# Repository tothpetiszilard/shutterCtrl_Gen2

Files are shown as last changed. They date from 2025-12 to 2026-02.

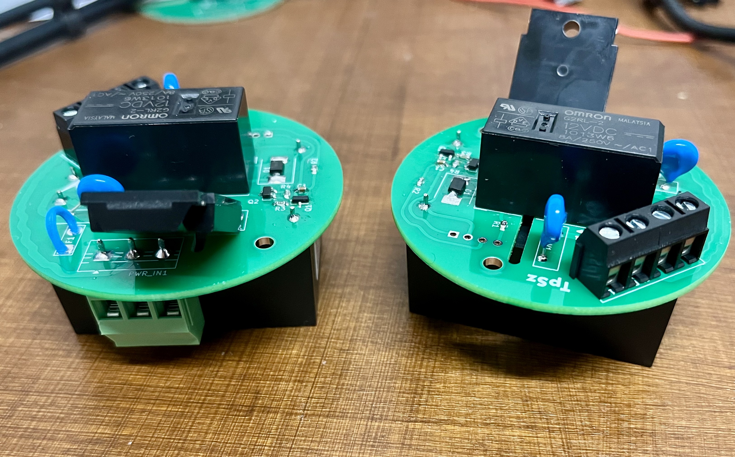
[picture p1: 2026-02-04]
pwr/images/IMG_6767.jpg

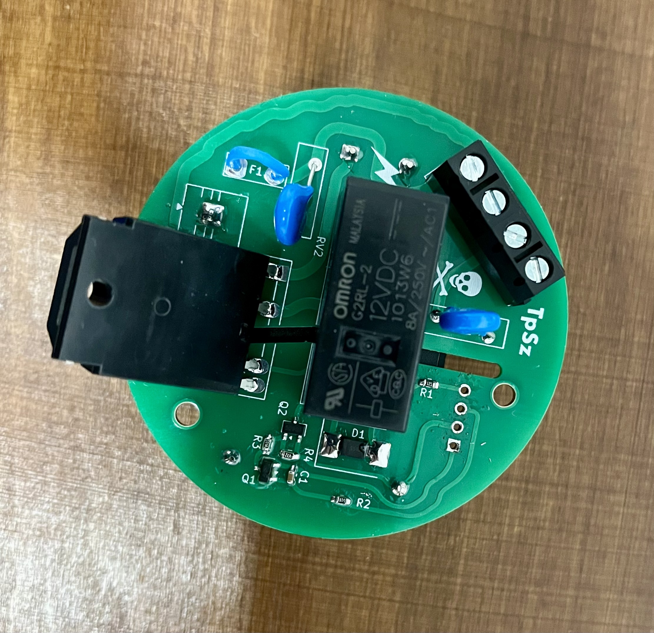
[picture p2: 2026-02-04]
pwr/images/IMG_6769.jpg

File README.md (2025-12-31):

# Development of an electric window shutter motor controller
- This is the second version of my project -> First version use two SSRs, this one use one SSR (zero-cross) and one relay
- The plan is to first select the direction with the relay, then turn on the motor with the SSR
- Varistors are not optional, they are required to protect the electronics
- There will be two boards, one for the high voltage components and one for the control logic
- There is a standard shutter ctrl switch (legrand) in the wall with 3 wires, that will be also utilized and will be connected to the controller board
- Shutter motor is generic, no electronic control, only internal end-stop switches (NC)
- Whole stuff should fit into an european standard 80mm round electric box
- Optional IR led is available on the controller board to control the AC units in the rooms (experimental)

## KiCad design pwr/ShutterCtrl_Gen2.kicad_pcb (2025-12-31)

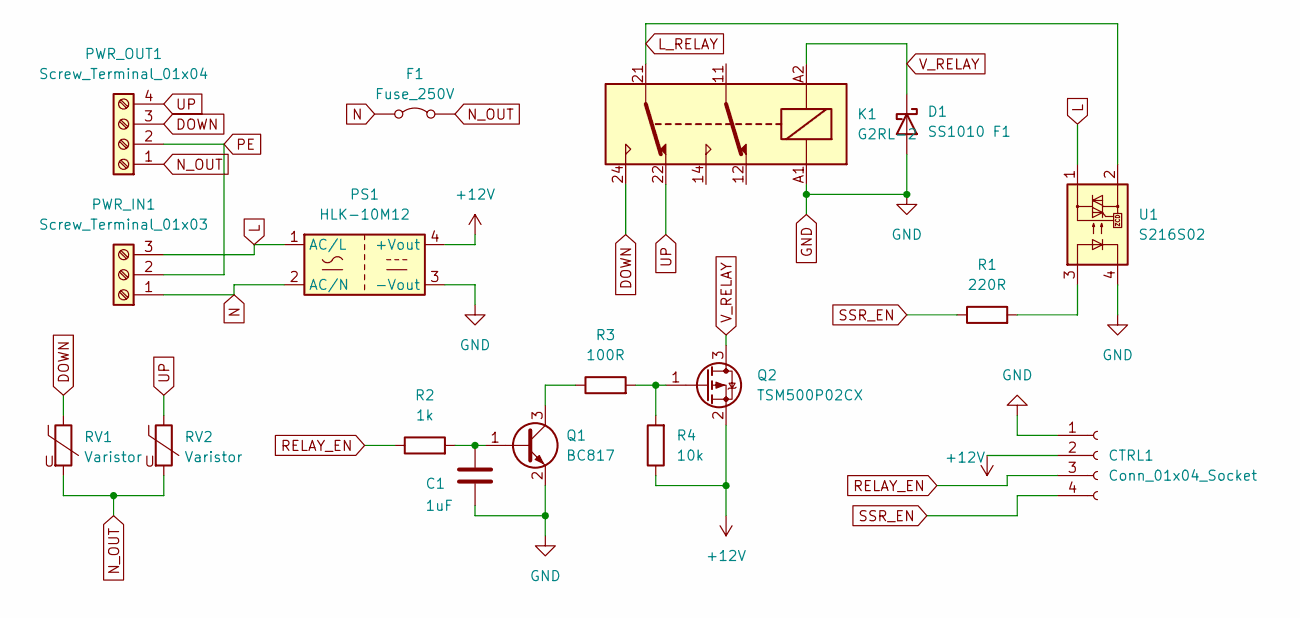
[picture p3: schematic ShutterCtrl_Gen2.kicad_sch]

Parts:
C1: 1uF; C_0603_1608Metric_Pad1.08x0.95mm_HandSolder
CTRL1: Conn_01x04_Socket; PinHeader_1x04_P2.54mm_Vertical
D1: SS1010 F1; D_SMC
F1: Fuse_250V; TestPoint_2Pads_Pitch5.08mm_Drill1.3mm
K1: G2RL-2; Relay_DPDT_Omron_G2RL-2
PS1: HLK-10M12; Converter_ACDC_Hi-Link_HLK-10Mxx
PWR_IN1: Screw_Terminal_01x03; TerminalBlock_MaiXu_MX126-5.0-03P_1x03_P5.00mm
PWR_OUT1: Screw_Terminal_01x04; TerminalBlock_MaiXu_MX126-5.0-04P_1x04_P5.00mm
Q1: BC817; SOT-23
Q2: TSM500P02CX; SOT-23
R1: 220R; R_0201_0603Metric_Pad0.64x0.40mm_HandSolder
R2: 1k; R_0201_0603Metric_Pad0.64x0.40mm_HandSolder
R3: 100R; R_0201_0603Metric_Pad0.64x0.40mm_HandSolder
R4: 10k; R_0201_0603Metric_Pad0.64x0.40mm_HandSolder
RV1, RV2: Varistor; RV_Disc_D12mm_W3.9mm_P7.5mm
U1: S216S02; SIP4_Sharp-SSR_P7.62mm_Straight

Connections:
+12V: CTRL1.2, PS1.4 (+Vout), Q2.2 (S), R4.1
DOWN: K1.24, PWR_OUT1.3, RV1.1
GND: C1.2, CTRL1.1, D1.2 (A), K1.A1, PS1.3 (-Vout), Q1.2 (E), U1.4
L: PS1.1 (AC/L), PWR_IN1.3, U1.1
L_RELAY: K1.21, U1.2
N: F1.1 (A), PS1.2 (AC/N), PWR_IN1.1
N_OUT: F1.2 (B), PWR_OUT1.1, RV1.2, RV2.2
unnamed: C1.1, Q1.1 (B), R2.2
unnamed: Q1.3 (C), R3.1
unnamed: Q2.1 (G), R3.2, R4.2
unnamed: R1.2, U1.3
PE: PWR_IN1.2, PWR_OUT1.2
RELAY_EN: CTRL1.3, R2.1
SSR_EN: CTRL1.4, R1.1
UP: K1.22, PWR_OUT1.4, RV2.1
V_RELAY: D1.1 (K), K1.A2, Q2.3 (D)

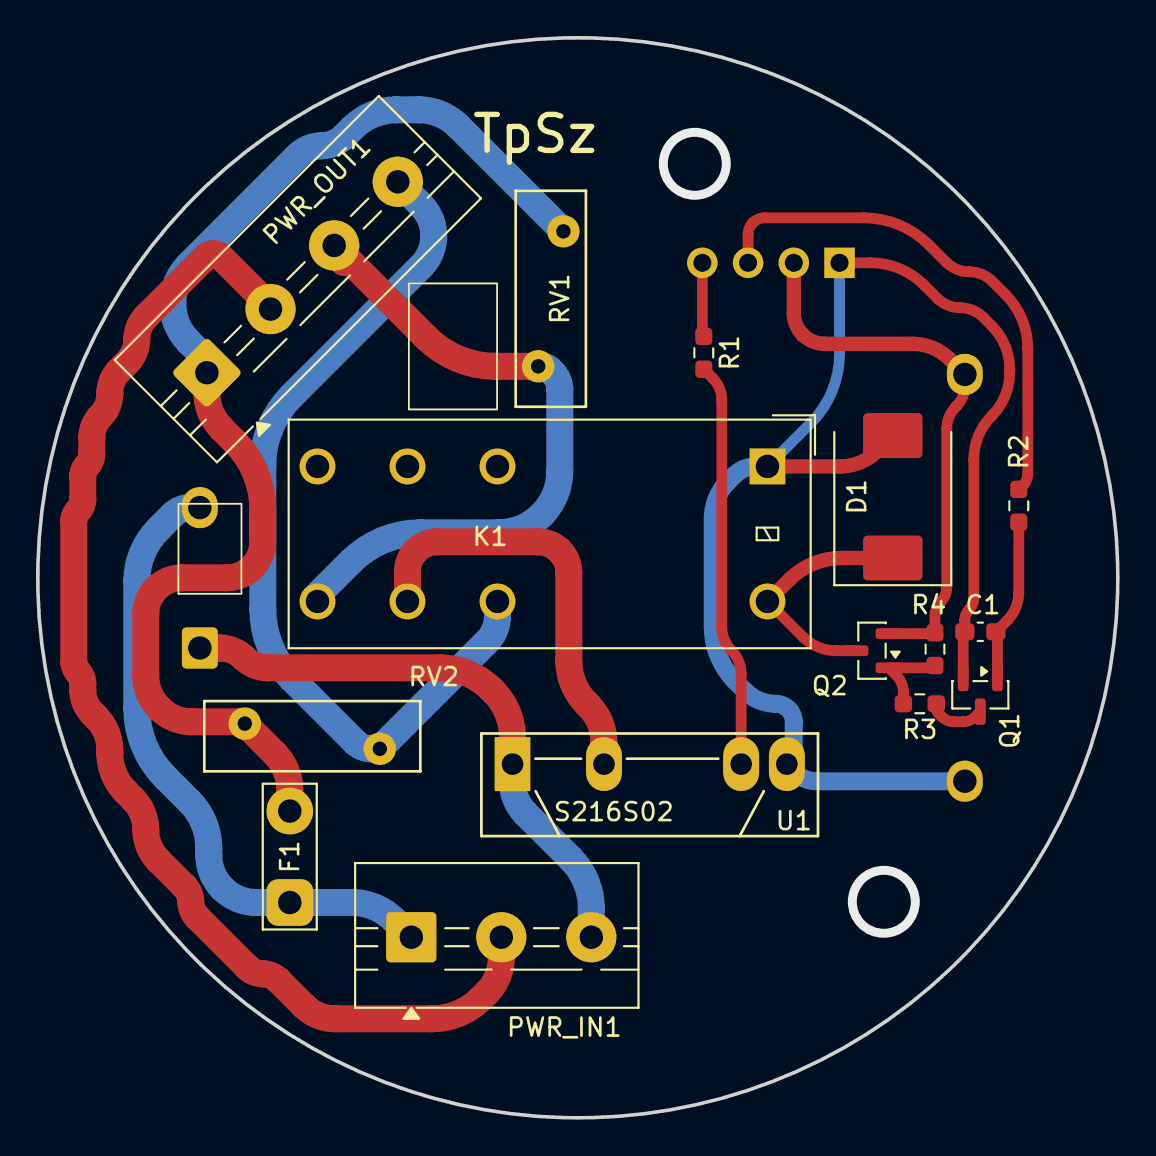
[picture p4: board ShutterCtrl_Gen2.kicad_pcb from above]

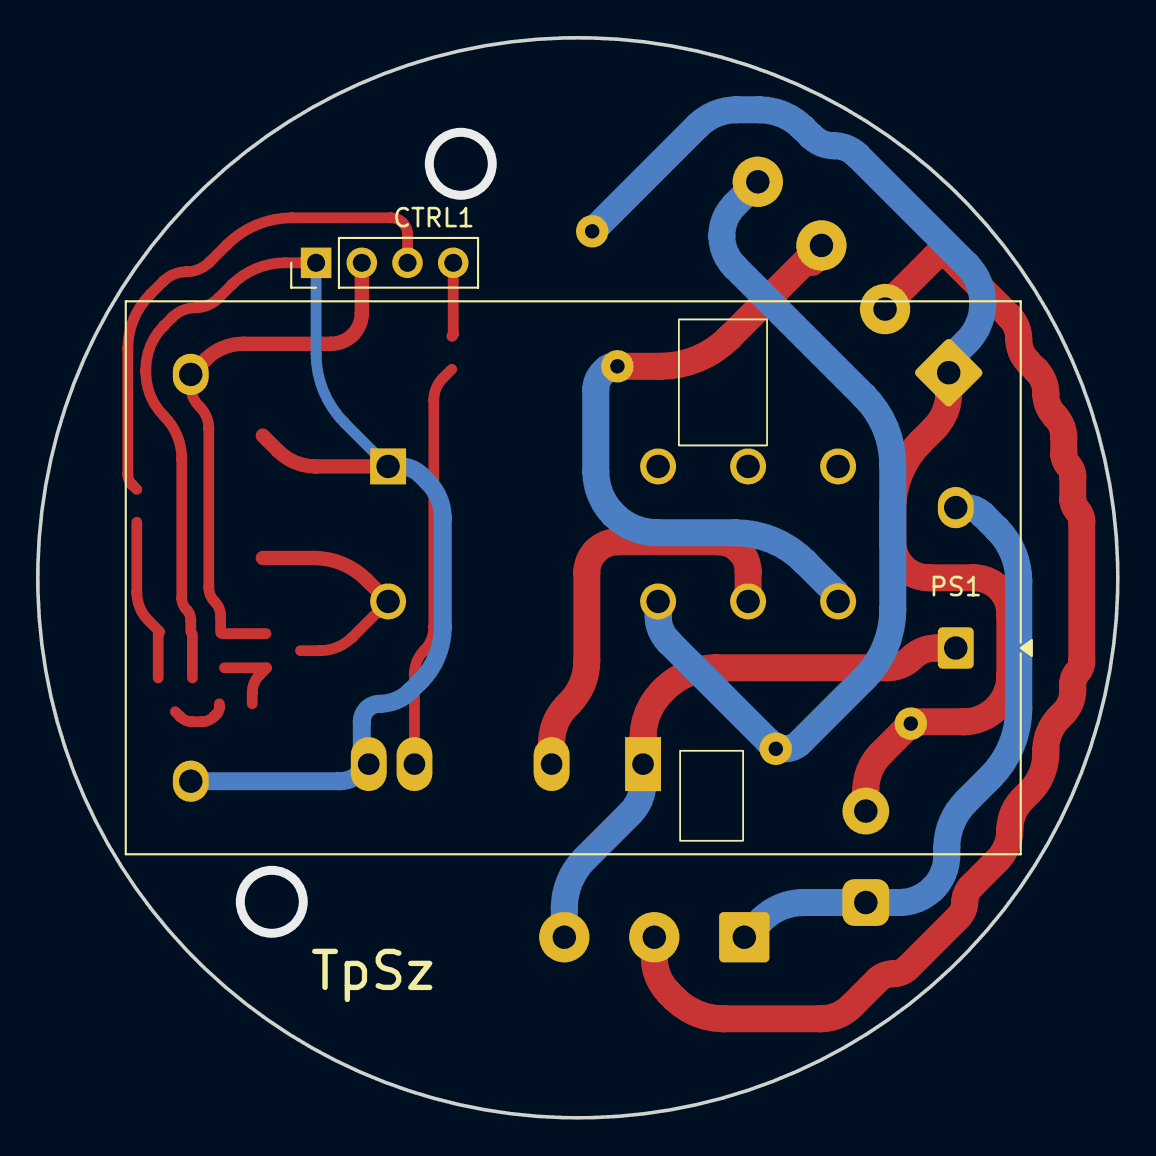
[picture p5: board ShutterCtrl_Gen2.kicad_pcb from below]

Board: 2 copper layers, 60.0 x 60.0 mm, 17 parts (2 on the bottom side), 16 nets.

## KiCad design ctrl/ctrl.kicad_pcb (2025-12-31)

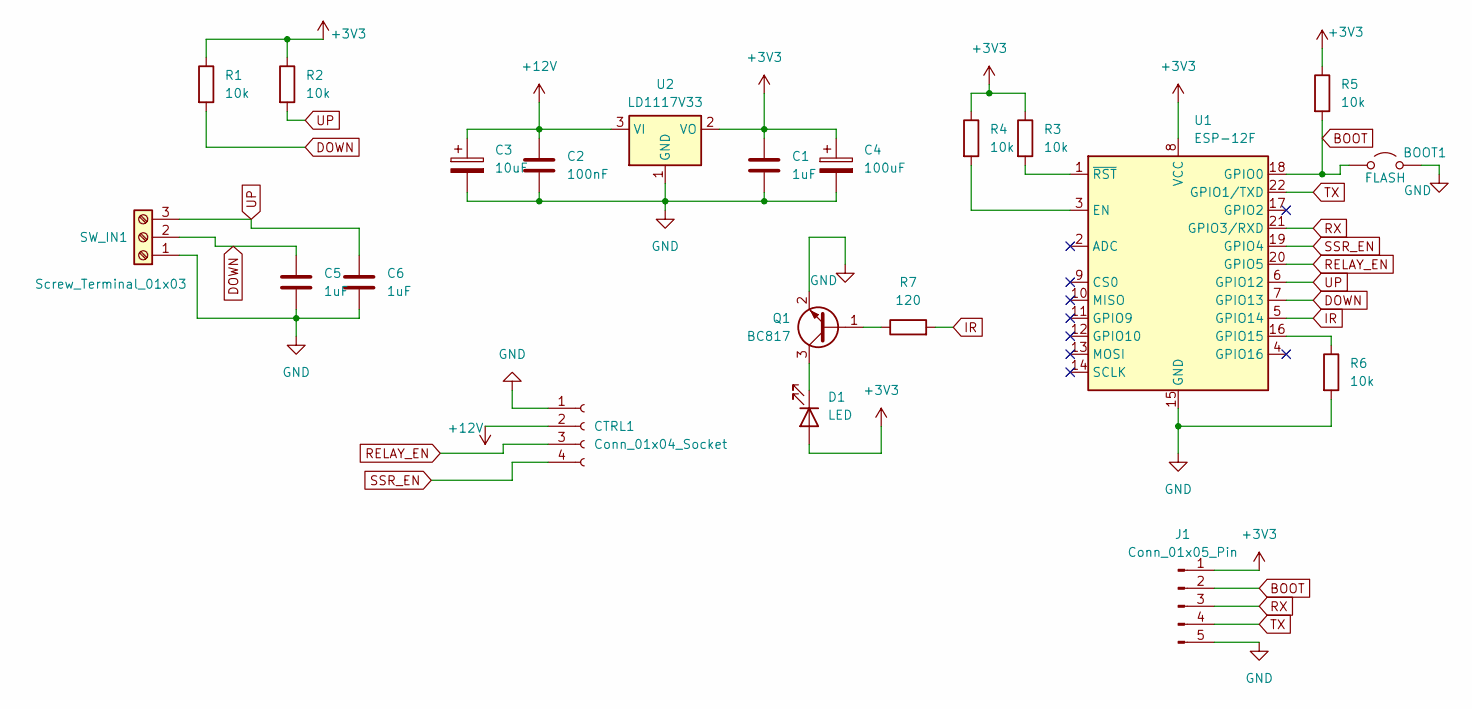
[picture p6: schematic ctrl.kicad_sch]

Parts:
BOOT1: FLASH; TestPoint_2Pads_Pitch2.54mm_Drill0.8mm
C1, C5, C6: 1uF; C_0603_1608Metric_Pad1.08x0.95mm_HandSolder
C2: 100nF; C_0603_1608Metric_Pad1.08x0.95mm_HandSolder
C3: 10uF; CP_Radial_Tantal_D4.5mm_P2.50mm
C4: 100uF; CP_Radial_D5.0mm_P2.00mm
CTRL1: Conn_01x04_Socket; PinHeader_1x04_P2.54mm_Vertical
D1: LED; LED_D5.0mm_Clear
J1: Conn_01x05_Pin; Molex_SL_171971-0005_1x05_P2.54mm_Vertical
Q1: BC817; SOT-23
R1, R2, R3, R4, R5, R6: 10k; R_0603_1608Metric_Pad0.98x0.95mm_HandSolder
R7: 120; R_0603_1608Metric_Pad0.98x0.95mm_HandSolder
SW_IN1: Screw_Terminal_01x03; TerminalBlock_MaiXu_MX126-5.0-03P_1x03_P5.00mm
U1: ESP-12F; ESP-12E
U2: LD1117V33; TO-220-3_Vertical

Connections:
+3V3: C1.1, C4.1, D1.2 (A), J1.1, R1.1, R2.1, R3.1, R4.1, R5.1, U1.8 (VCC), U2.2 (VO)
+12V: C2.1, C3.1, CTRL1.2, U2.3 (VI)
BOOT: BOOT1.1 (A), J1.2, R5.2, U1.18 (GPIO0)
DOWN: C5.1, R1.2, SW_IN1.2, U1.7 (GPIO13)
GND: BOOT1.2 (B), C1.2, C2.2, C3.2, C4.2, C5.2, C6.2, CTRL1.1, J1.5, Q1.2 (E), R6.2, SW_IN1.1, U1.15 (GND), U2.1 (GND)
IR: R7.2, U1.5 (GPIO14)
unnamed: D1.1 (K), Q1.3 (C)
unnamed: Q1.1 (B), R7.1
unnamed: R4.2, U1.3 (EN)
unnamed: R6.1, U1.16 (GPIO15)
unnamed: R3.2, U1.1 (~RST)
RELAY_EN: CTRL1.3, U1.20 (GPIO5)
RX: J1.3, U1.21 (GPIO3/RXD)
SSR_EN: CTRL1.4, U1.19 (GPIO4)
TX: J1.4, U1.22 (GPIO1/TXD)
UP: C6.1, R2.2, SW_IN1.3, U1.6 (GPIO12)

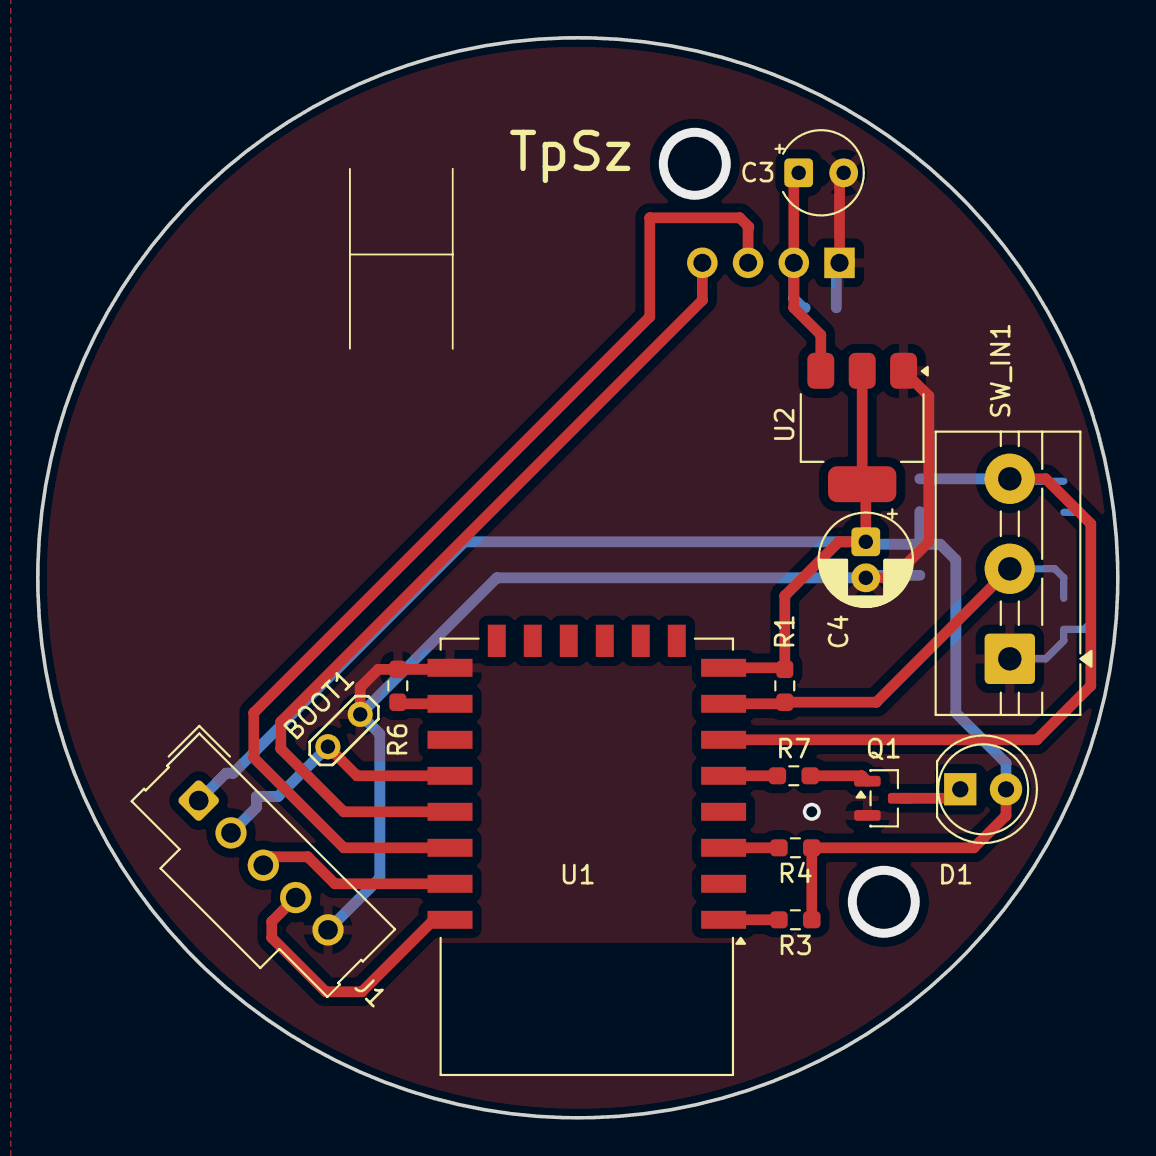
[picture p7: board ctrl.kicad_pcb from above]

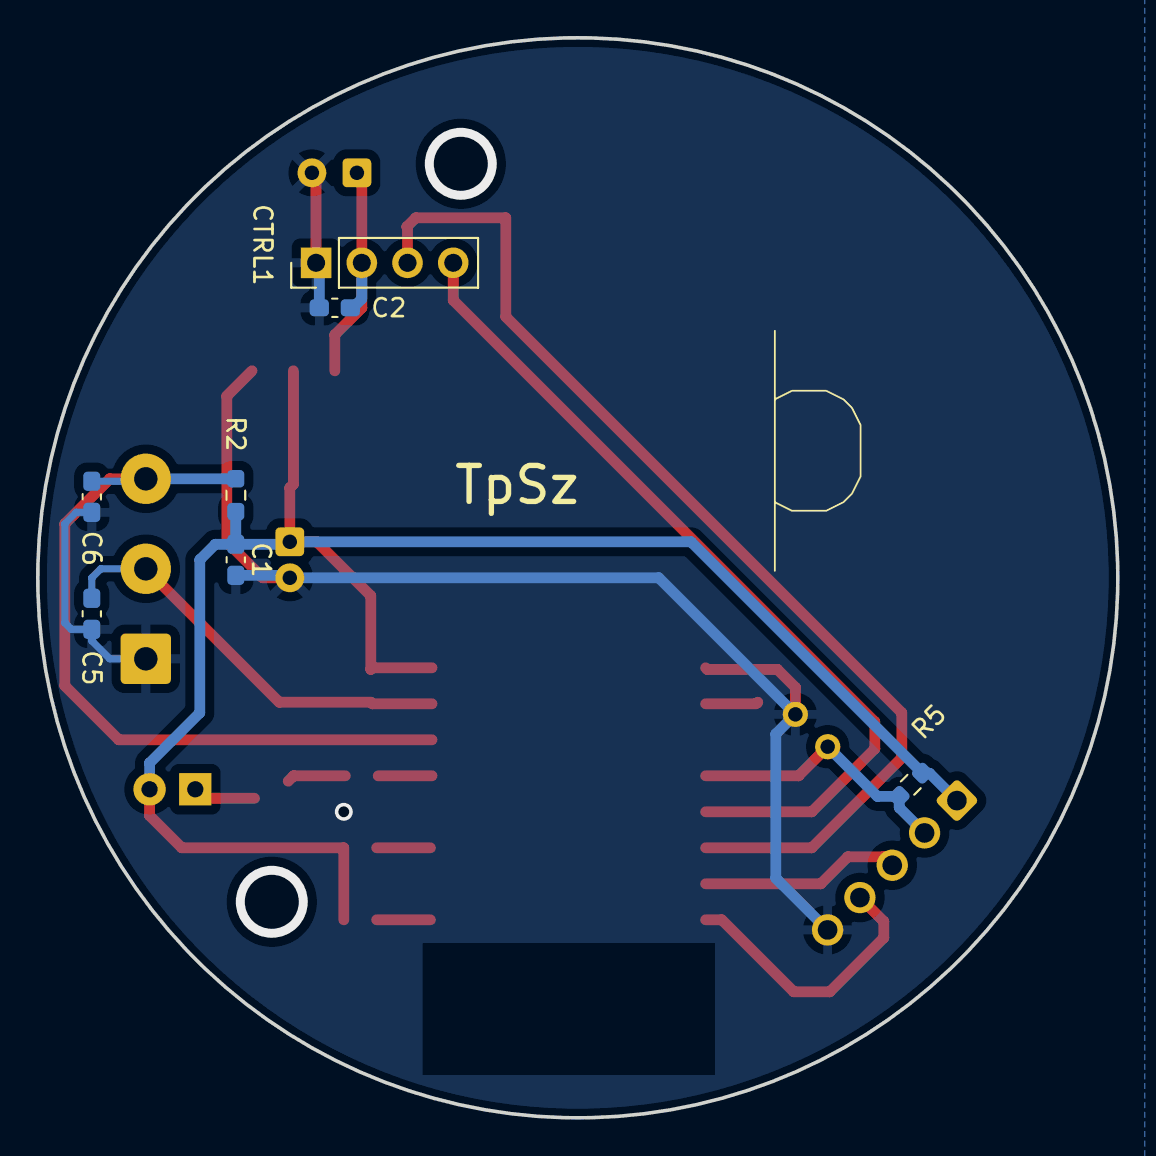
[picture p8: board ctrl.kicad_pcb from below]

Board: 2 copper layers, 60.0 x 60.0 mm, 21 parts (7 on the bottom side), 16 nets.

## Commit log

2025-12-31 Initial version - PWR board designed
    [ShutterCtrl_Gen2.kicad_pcb, ShutterCtrl_Gen2.kicad_sch]
2025-12-31 First version of HW design
    [ShutterCtrl_Gen2.kicad_pcb, ShutterCtrl_Gen2.kicad_sch, ctrl.kicad_pcb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]
2025-12-31 Updated kicad project file
2025-12-31 PCB size was wrong, complete redesign...
    [ShutterCtrl_Gen2.kicad_pcb, ctrl.kicad_pcb]
2026-02-04 Pictures about the assembled power unit
